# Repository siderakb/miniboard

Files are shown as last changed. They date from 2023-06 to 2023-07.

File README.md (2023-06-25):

# Miniboard

A super mini keyboard.

## Disclaimer

These files are provided without warranty of any kind.  
Including but not limited to manufacturing, assembly, procurement and use at your own risk.  
It is recommended to check yourself before use.  

For the full statement, please see [LICENSE](./LICENSE).

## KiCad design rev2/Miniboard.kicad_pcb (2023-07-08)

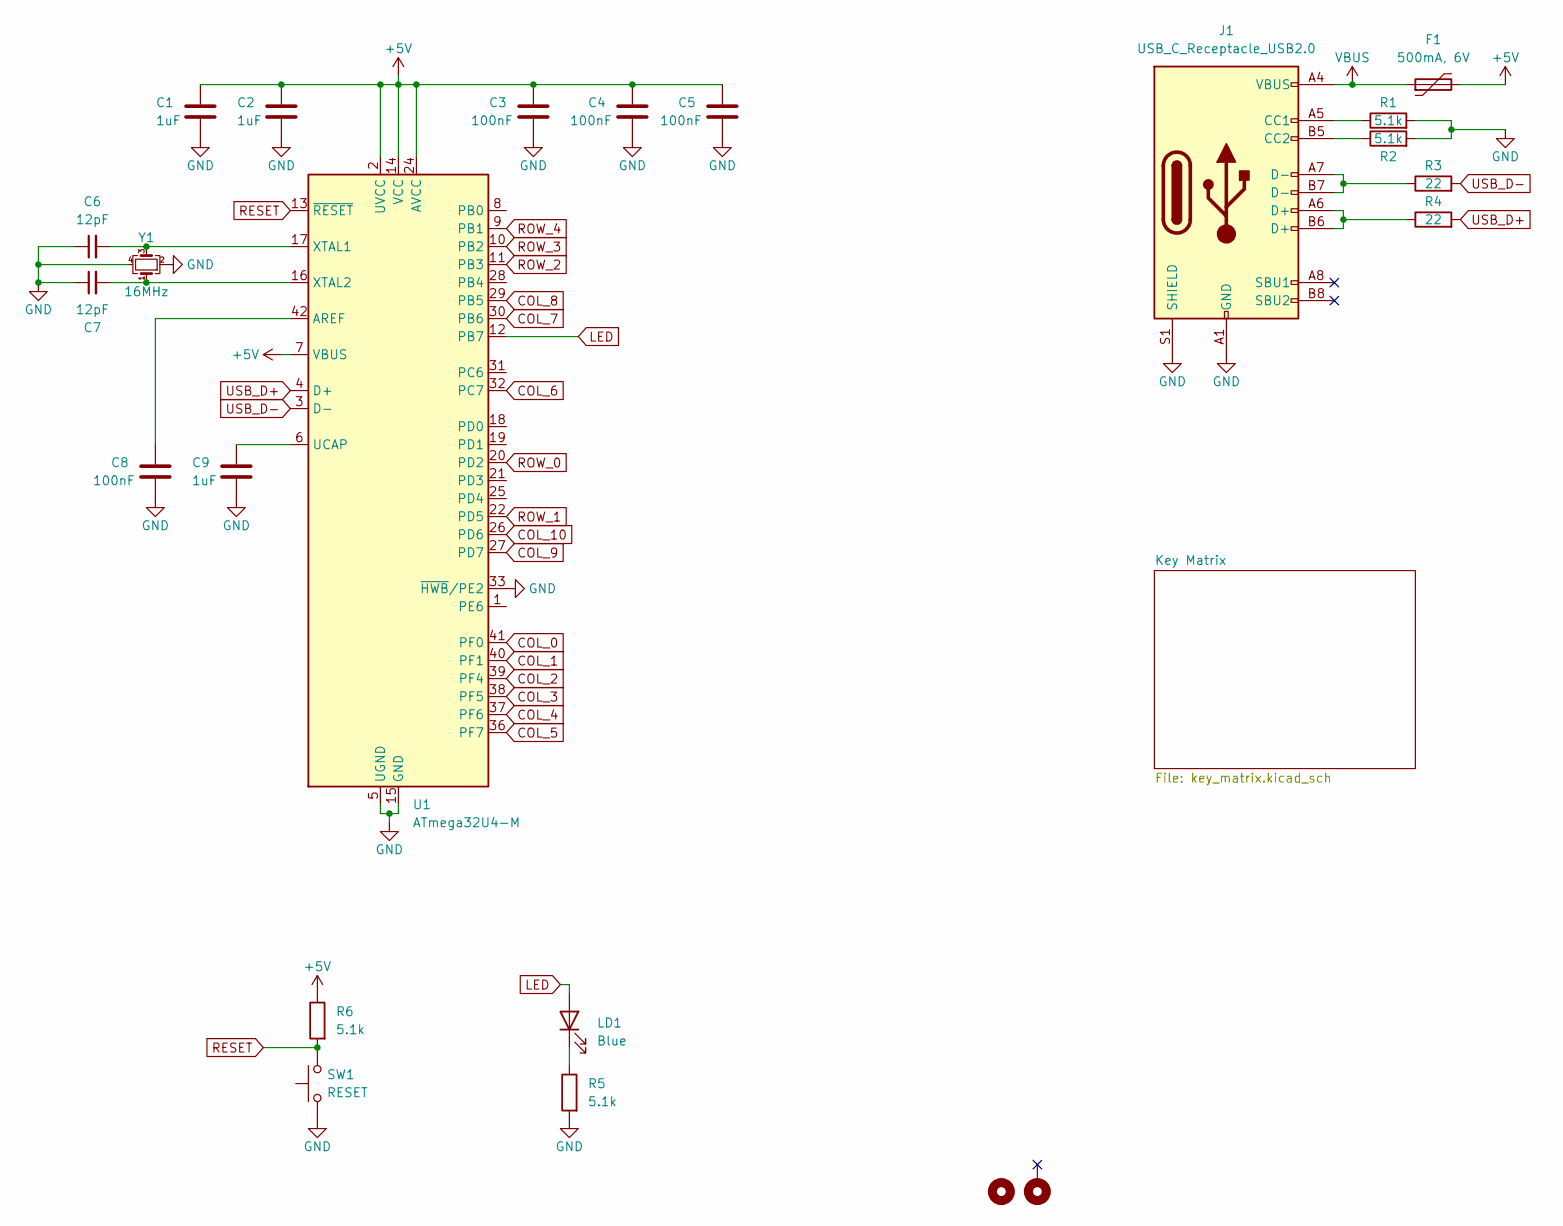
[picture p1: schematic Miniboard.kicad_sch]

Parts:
C1, C2, C9: 1uF; C_0402_1005Metric; MFR. Part # CL05A105KA5NQNC; LCSC C52923
C3, C4, C5, C8: 100nF; C_0402_1005Metric; MFR. Part # CL05B104KO5NNNC; LCSC C1525
C6, C7: 12pF; C_0402_1005Metric; MFR. Part # 0402CG120J500NT; LCSC C1547
F1: 500mA, 6V; Fuse_0805_2012Metric; MFR. Part # SMD0805B050TF; LCSC C269104
H2: MountingHole
H3: MountingHole_Pad; MountingHole_2.2mm_M2_DIN965_Pad
J1: USB_C_Receptacle_USB2.0; USB-C_16p_918-418K2023S40023; MFR. Part # 918-418K2023S40023; LCSC C709031
LD1: Blue; LED_0603_1608Metric; MFR. Part # 19-217/GHC-YR1S2/3T; LCSC C72043
R1, R2, R5, R6: 5.1k; R_0402_1005Metric; MFR. Part # 0402WGF5101TCE; LCSC C25905
R3, R4: 22; R_0402_1005Metric; MFR. Part # CRCW040222R0FKED; LCSC C482106
SW1: RESET; SW_SPST_B3U-1000P; MFR. Part # B3U-1000P; LCSC C231329
U1: ATmega32U4-M; QFN-44-1EP_7x7mm_P0.5mm_EP5.2x5.2mm; MFR. Part # ATMEGA32U4-MU; LCSC C112161
Y1: 16MHz; Crystal_SMD_2016-4Pin_2.0x1.6mm; MFR. Part # XL7EL89COI-111YLC-16M; LCSC C2965579

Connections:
+5V: C1.1, C2.1, C3.1, C4.1, C5.1, F1.2, R6.1, U1.2 (UVCC), U1.7 (VBUS), U1.14 (VCC), U1.24 (AVCC), U1.34 (VCC), U1.44 (AVCC)
COL_0: U1.41 (PF0); also elsewhere on the board
COL_1: U1.40 (PF1); also elsewhere on the board
COL_2: U1.39 (PF4); also elsewhere on the board
COL_3: U1.38 (PF5); also elsewhere on the board
COL_4: U1.37 (PF6); also elsewhere on the board
COL_5: U1.36 (PF7); also elsewhere on the board
COL_6: U1.32 (PC7); also elsewhere on the board
COL_7: U1.30 (PB6); also elsewhere on the board
COL_8: U1.29 (PB5); also elsewhere on the board
COL_9: U1.27 (PD7); also elsewhere on the board
COL_10: U1.26 (PD6); also elsewhere on the board
GND: C1.2, C2.2, C3.2, C4.2, C5.2, C6.1, C7.1, C8.2, C9.2, J1.A1 (GND), J1.A12 (GND), J1.B1 (GND), J1.B12 (GND), J1.S1 (SHIELD), R1.2, R2.2, R5.2, SW1.1, U1.5 (UGND), U1.15 (GND), U1.23 (GND), U1.33 (~HWB/PE2), U1.35 (GND), U1.43 (GND), U1.45 (GND), Y1.2, Y1.4
LED: LD1.2 (A), U1.12 (PB7)
unnamed: J1.A5 (CC1), R1.1
unnamed: J1.B5 (CC2), R2.1
unnamed: J1.A6 (D+), J1.B6 (D+), R4.1
unnamed: J1.A7 (D-), J1.B7 (D-), R3.1
unnamed: LD1.1 (K), R5.1
unnamed: C8.1, U1.42 (AREF)
unnamed: C9.1, U1.6 (UCAP)
unnamed: C6.2, U1.17 (XTAL1), Y1.3
unnamed: C7.2, U1.16 (XTAL2), Y1.1
RESET: R6.2, SW1.2, U1.13 (~RESET)
ROW_0: U1.20 (PD2); also elsewhere on the board
ROW_1: U1.22 (PD5); also elsewhere on the board
ROW_2: U1.11 (PB3); also elsewhere on the board
ROW_3: U1.10 (PB2); also elsewhere on the board
ROW_4: U1.9 (PB1); also elsewhere on the board
USB_D+: R4.2, U1.4 (D+)
USB_D-: R3.2, U1.3 (D-)
VBUS: F1.1, J1.A4 (VBUS), J1.A9 (VBUS), J1.B4 (VBUS), J1.B9 (VBUS)

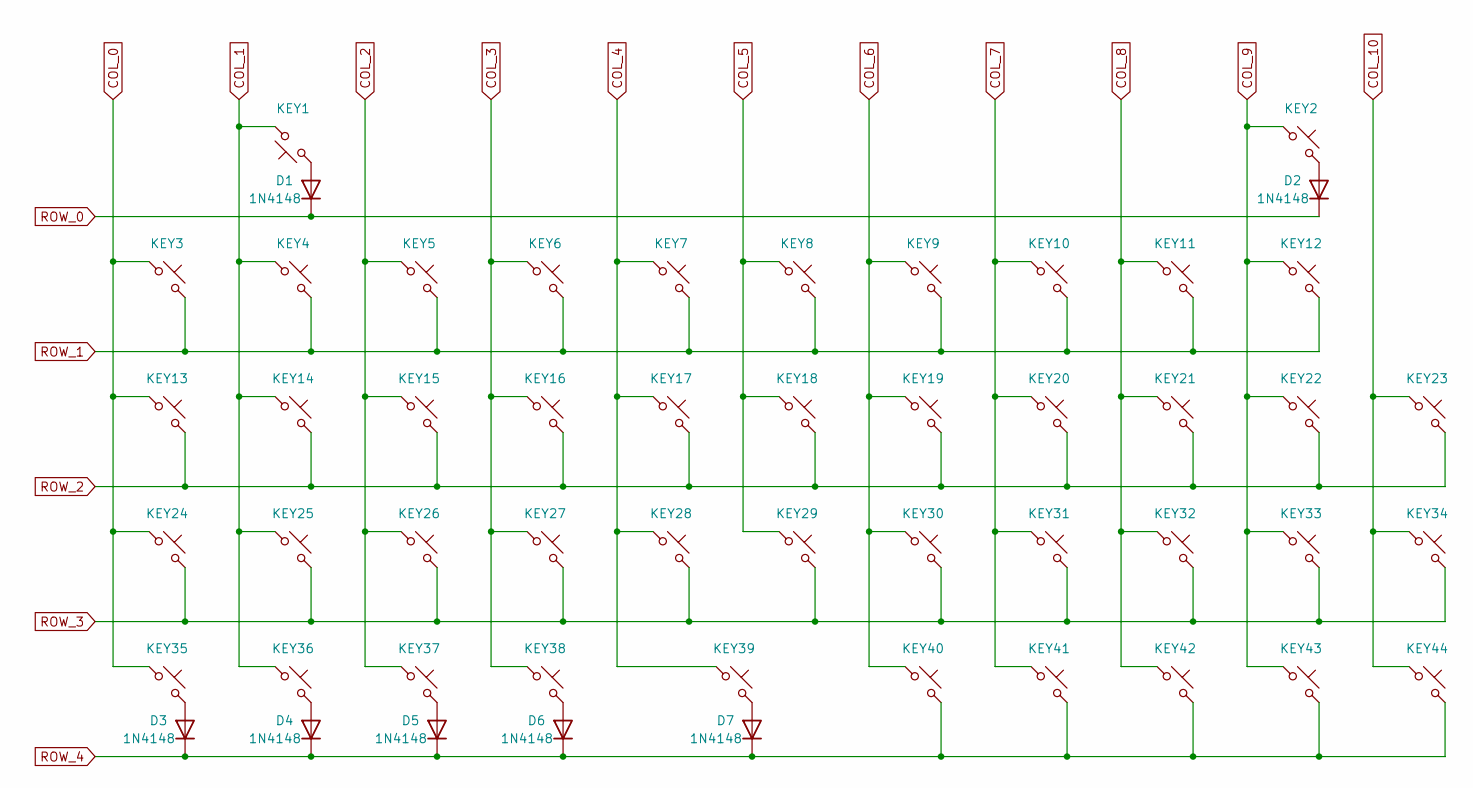
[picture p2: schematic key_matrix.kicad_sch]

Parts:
D1, D2, D3, D4, D5, D6, D7: 1N4148; D_SOD-323_HandSoldering; MFR. Part # 1N4148WS; LCSC C2128
KEY1, KEY2: SW_Push_45deg; SW_2x4x3.5mm_side; MFR. Part # TS24CA; LCSC C393942
KEY3, KEY4, KEY5, KEY6, KEY7, KEY8, KEY9, KEY10, KEY11, KEY12, KEY13, KEY14, KEY15, KEY16, KEY17, KEY18, KEY19, KEY20, KEY21, KEY22, KEY23, KEY24, KEY25, KEY26, KEY27, KEY28, KEY29, KEY30, KEY31, KEY32, KEY33, KEY34, KEY35, KEY36, KEY37, KEY38, KEY39, KEY40, KEY41, KEY42, KEY43, KEY44: SW_Push_45deg; SW_1TS015A; MFR. Part # 1TS015A-1800-0600-CT; LCSC C256105

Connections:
COL_0: KEY3.1, KEY13.1, KEY24.1, KEY35.1; also elsewhere on the board
COL_1: KEY1.2, KEY4.1, KEY14.1, KEY25.1, KEY36.1; also elsewhere on the board
COL_2: KEY5.1, KEY15.1, KEY26.1, KEY37.1; also elsewhere on the board
COL_3: KEY6.1, KEY16.1, KEY27.1, KEY38.1; also elsewhere on the board
COL_4: KEY7.1, KEY17.1, KEY28.1, KEY39.1; also elsewhere on the board
COL_5: KEY8.1, KEY18.1, KEY29.1; also elsewhere on the board
COL_6: KEY9.1, KEY19.1, KEY30.1, KEY40.1; also elsewhere on the board
COL_7: KEY10.1, KEY20.1, KEY31.1, KEY41.1; also elsewhere on the board
COL_8: KEY11.1, KEY21.1, KEY32.1, KEY42.1; also elsewhere on the board
COL_9: KEY2.1, KEY12.1, KEY22.1, KEY33.1, KEY43.1; also elsewhere on the board
COL_10: KEY23.1, KEY34.1, KEY44.1; also elsewhere on the board
unnamed: D1.2 (A), KEY1.1
unnamed: D2.2 (A), KEY2.2
unnamed: D3.2 (A), KEY35.2
unnamed: D4.2 (A), KEY36.2
unnamed: D5.2 (A), KEY37.2
unnamed: D6.2 (A), KEY38.2
unnamed: D7.2 (A), KEY39.2
ROW_0: D1.1 (K), D2.1 (K); also elsewhere on the board
ROW_1: KEY3.2, KEY4.2, KEY5.2, KEY6.2, KEY7.2, KEY8.2, KEY9.2, KEY10.2, KEY11.2, KEY12.2; also elsewhere on the board
ROW_2: KEY13.2, KEY14.2, KEY15.2, KEY16.2, KEY17.2, KEY18.2, KEY19.2, KEY20.2, KEY21.2, KEY22.2, KEY23.2; also elsewhere on the board
ROW_3: KEY24.2, KEY25.2, KEY26.2, KEY27.2, KEY28.2, KEY29.2, KEY30.2, KEY31.2, KEY32.2, KEY33.2, KEY34.2; also elsewhere on the board
ROW_4: D3.1 (K), D4.1 (K), D5.1 (K), D6.1 (K), D7.1 (K), KEY40.2, KEY41.2, KEY42.2, KEY43.2, KEY44.2; also elsewhere on the board

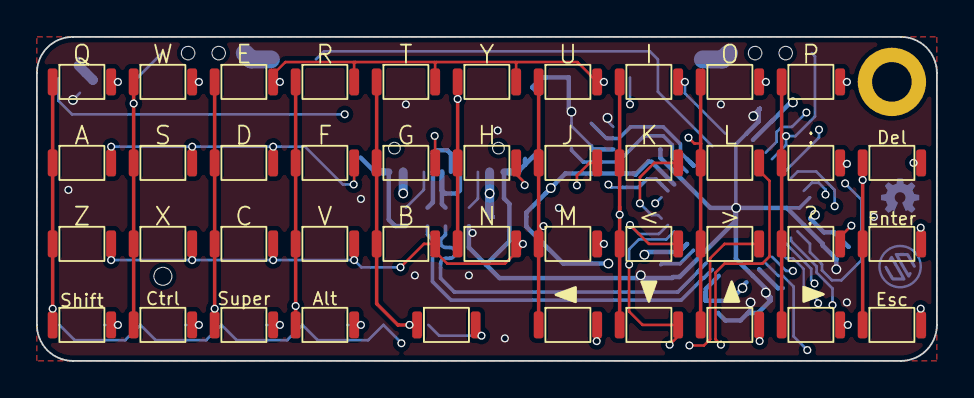
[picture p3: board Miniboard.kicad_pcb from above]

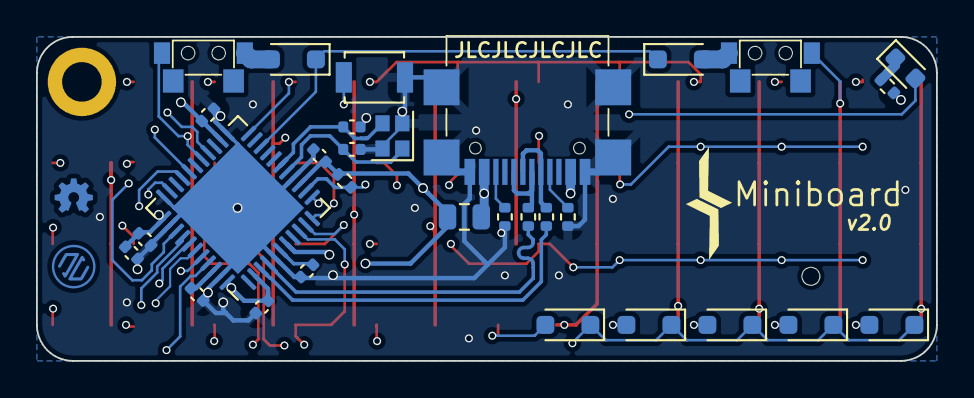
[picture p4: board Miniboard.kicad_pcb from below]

Board: 4 copper layers, 50.0 x 18.0 mm, 74 parts (30 on the bottom side), 39 nets.

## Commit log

2023-06-22 Init commit
    [MCU.kicad_sch, Miniboard.kicad_pcb, Miniboard.kicad_sch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]
2023-06-23 Move rev1 PCB files
    [Miniboard.kicad_pcb, Miniboard.kicad_sch, key_matrix.kicad_sch]
2023-06-23 Rev2.0 init
    [Miniboard.kicad_pcb, Miniboard.kicad_sch, key_matrix.kicad_sch]
2023-06-25 Update Rev2
    [Miniboard.kicad_pcb]
2023-06-25 Update Rev1.0 silkscreen
    [Miniboard.kicad_pcb, Miniboard.kicad_sch, key_matrix.kicad_sch]
2023-07-08 Update BOM
    [Miniboard.kicad_pcb, Miniboard.kicad_sch, key_matrix.kicad_sch]

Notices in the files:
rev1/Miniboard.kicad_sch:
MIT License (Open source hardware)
